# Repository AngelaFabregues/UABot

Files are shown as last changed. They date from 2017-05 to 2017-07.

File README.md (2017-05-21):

# UABot
Robot imprimible específicament dissenyat per fer un taller de robòtica educativa a la Universitat Autònoma de Barcelona (UAB).

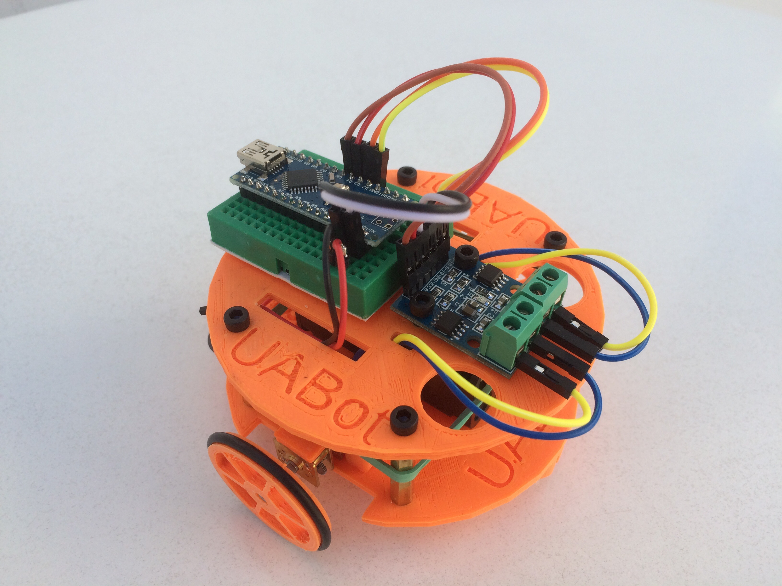
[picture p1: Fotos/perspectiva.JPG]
UABot


## Història
El Juliol 2017 es duu a terme un taller de robòtica anuncia com a Curs d'Estiu ICE de la UAB per a estudiants de 4t d'ESO i batxillerat. Durant el taller, els estudiants muntaran i programaran un robot dissenyat específicament per aquest taller. Aquest robot rep el nom d'UABot fent referència a la Universitat i a 'bot' (diminutiu de robot molt popular en grups de robòtica online).

## Disseny
Pel disseny de l'UABot s'ha buscat el robot que actualment cobreix millor les necessitats d'aquest taller i s'ha modificat per tal de satisfer-ne totes les necessitats. El robot en el que es basa principalment l'UABot és [Sapoconcho](https://bricolabs.cc/wiki/proyectos/sapoconcho).

A part de numeroses petites modificacions per a simplificar enormement la construcció del robot, l'UABot fa servir dues boles de moviment lliure enlloc d'una i porta les piles al centre suggectades per un elàstic. Això incrementa enórmement la robustessa i estabilitat del robot, i facilita el canvi de piles (que s'aconsella siguin recarregables).

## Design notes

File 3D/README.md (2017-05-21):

# UABot - 3D
El disseny dels components imprimibles s'ha realitzat íntegrament amb OpenScad. Això facilita la seva visualització i modificació.

## Impressió

Els components imprimibles a utilitzar al curs s'imprimeixen en diverses impressores replicables tipus Prusa IT2 i IT3 amb filament ABS o PLA de 3mm o 1'75 mm. Per a l'elecció s'ha tingut en compte sobretot la disponibilitat de les impressores en cada moment. Els components poden imprimir-se tots en una sola impressora i amb qualsevol d'aquests tipus de material i gruix de filament.

A més del curs d'estiu de l'ICE '' que ha motivat la creació de l'UABot, també es duu a terme un altre curs d'impressió 3D que proporciona la formació bàsica per a ser impressor 3D. Es tracta d'un curs molt interessant per qualsevol que vulgui crear un UABot imprimint-se les parts imprimibles.

## Parts imprimibles
* suport del motor: Facilita la fixació dels dos motors fent servir dos perns M2. També protegeix la connexió elèctrica al motor aportant una ranura per a enganxar-hi els cables.
* roda: 
* capa base: 
* capa control:

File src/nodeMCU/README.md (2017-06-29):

 

 per a poder installar l'entorn per a poder programar le nodeMCU 
 Open up Arduino, then go to the Preferences (File > Preferences). Then, towards the bottom of the window, 
 copy this URL into the “Additional Board Manager URLs” text box:
 
 http://arduino.esp8266.com/stable/package_esp8266com_index.json

Hit OK. Then navigate to the Board Manager by going to Tools > Boards > Boards Manager.
There should be a couple new entries in addition to the standard Arduino boards.
Look for esp8266. Click on that entry, then select Install.

tutorial interesante
http://www.instructables.com/id/Quick-Start-to-Nodemcu-ESP8266-on-Arduino-IDE/

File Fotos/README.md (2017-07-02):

UABot perspectiva
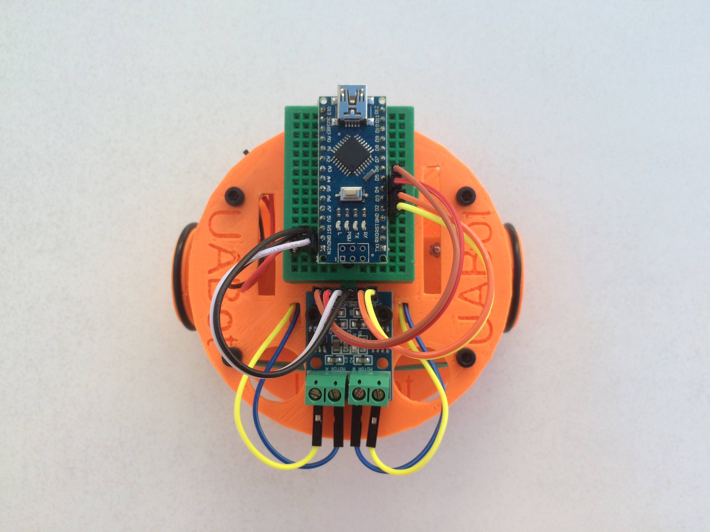
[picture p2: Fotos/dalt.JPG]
UABot dalt

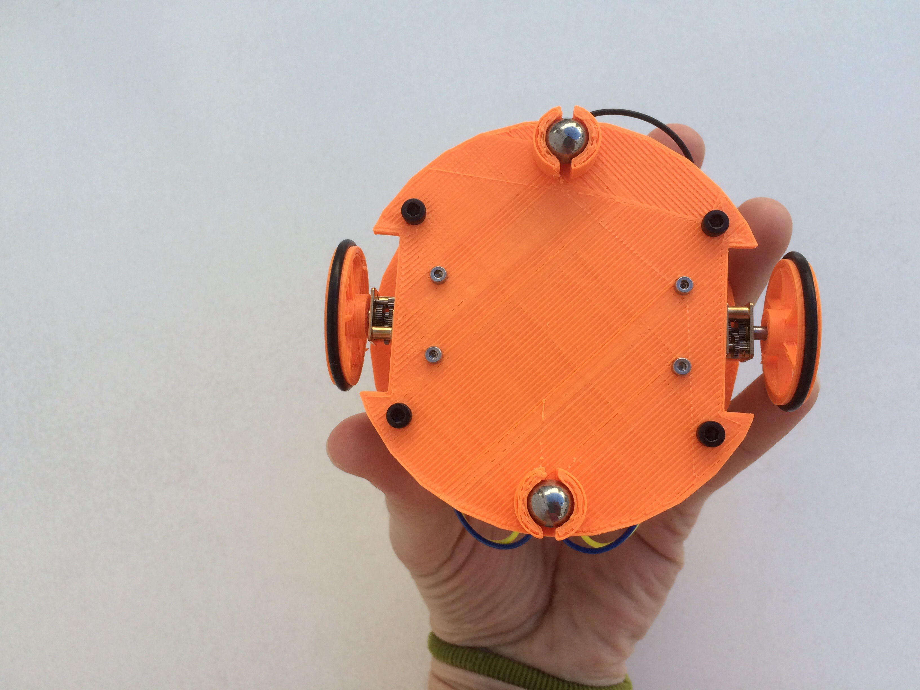
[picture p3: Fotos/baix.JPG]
UABot baix

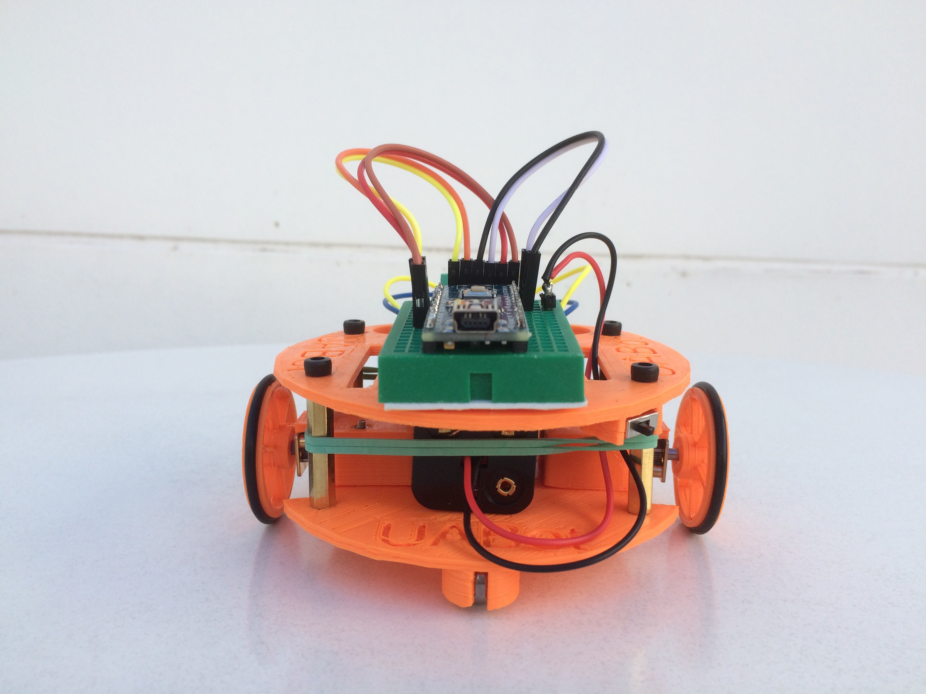
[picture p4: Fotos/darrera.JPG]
UABot darrera

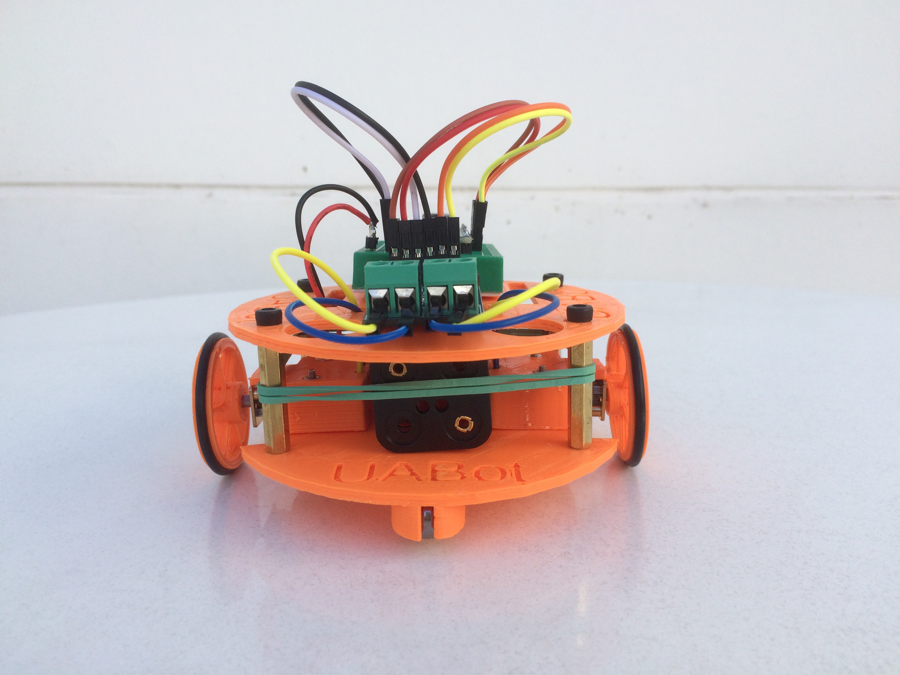
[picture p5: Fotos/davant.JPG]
UABot davant

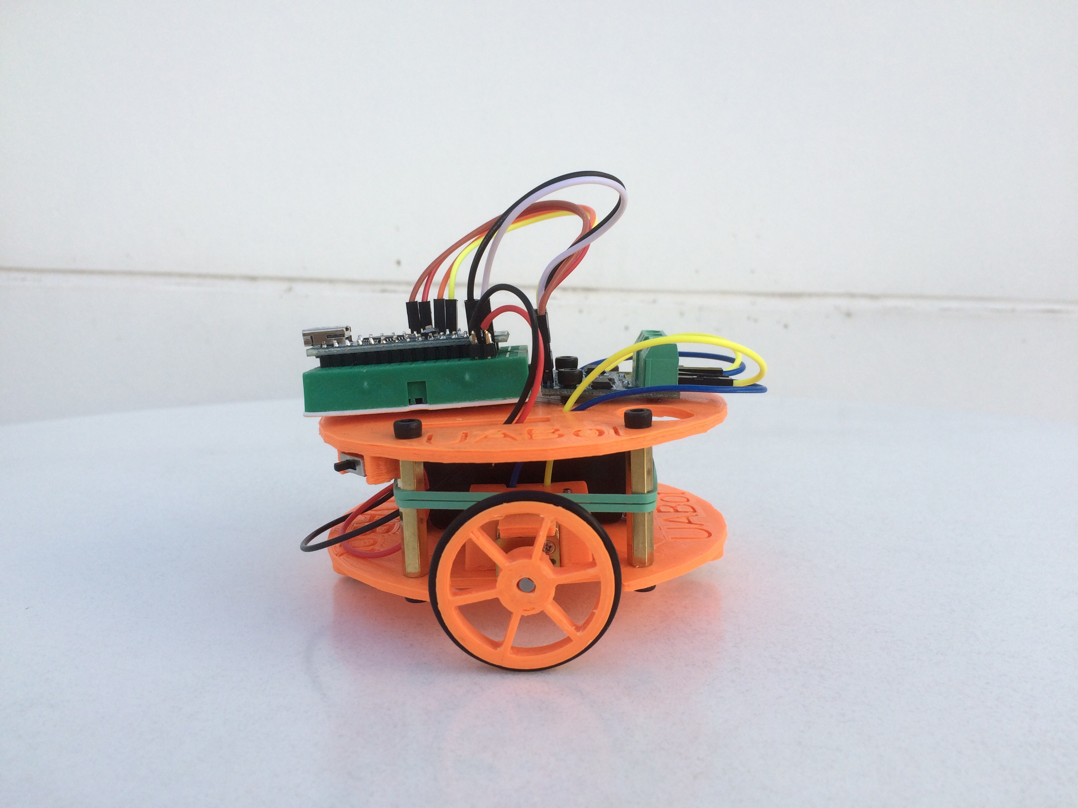
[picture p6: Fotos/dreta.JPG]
UABot dreta

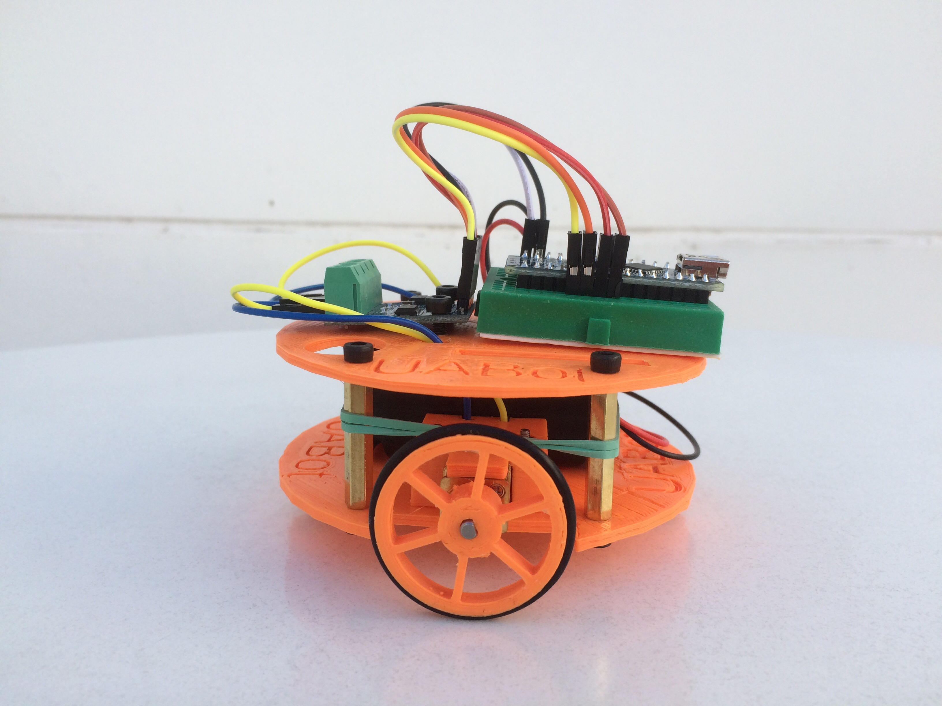
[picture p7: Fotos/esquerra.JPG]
UABot esquerra


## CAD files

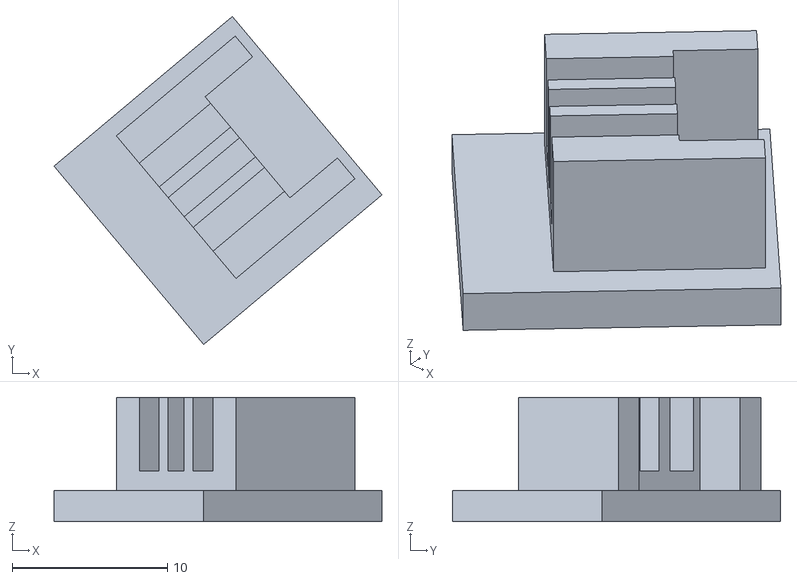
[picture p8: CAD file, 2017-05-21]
3D/suportMicroInterruptor.stl
21.1 x 21.1 x 8.00

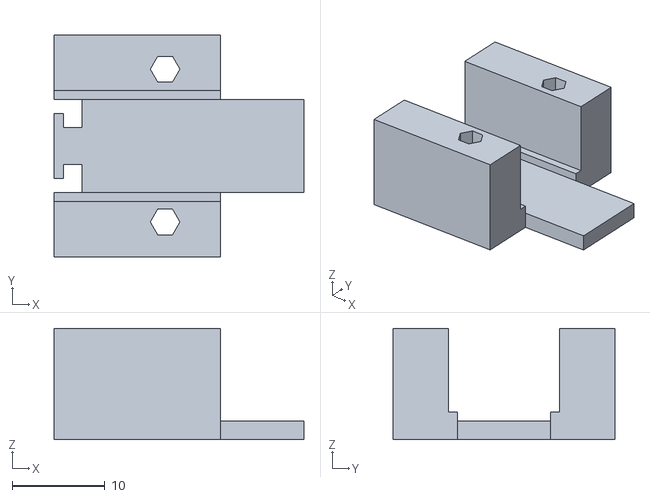
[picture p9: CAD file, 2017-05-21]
3D/suportMotor.stl
27.0 x 24.0 x 12.0

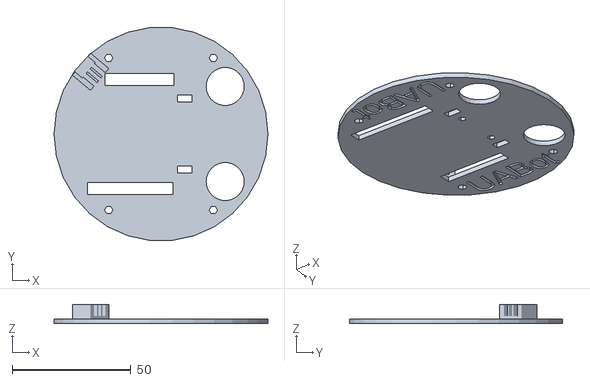
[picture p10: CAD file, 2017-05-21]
3D/capaControl.stl
90.0 x 89.5 x 8.00

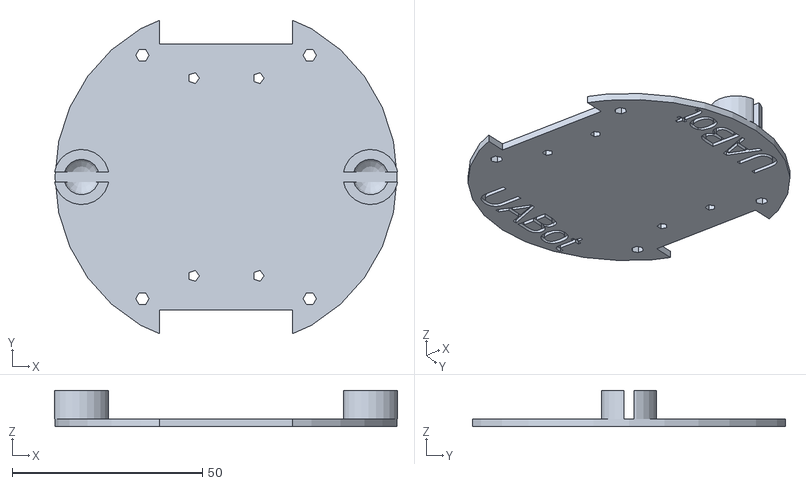
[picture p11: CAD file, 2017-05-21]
3D/capaBase.stl
90.2 x 82.4 x 9.50

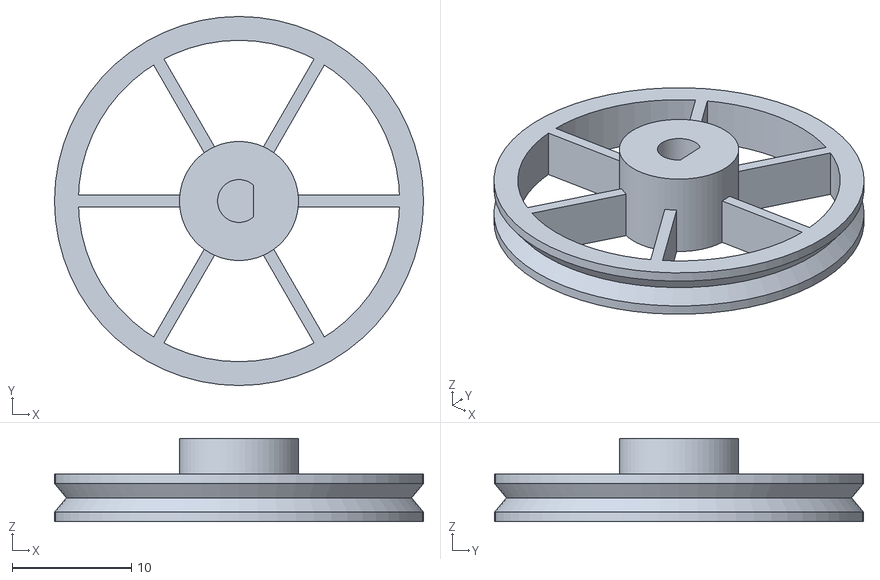
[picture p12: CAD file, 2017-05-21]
3D/roda.stl
31.0 x 31.0 x 7.00

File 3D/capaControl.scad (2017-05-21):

// Capa control amb forats per suggectar a placa base, forats per cables dels motors, forats per suggectar controllador motor, suport microinterruptor
module letter(l,s,h) {
	linear_extrude(height = h) {
		text(l, size = s, font = "Veltica", halign = "center", valign = "center", $fn = 16);
	}
}

module suportMicroInterruptor(t,r){
    rotate(r){ // interruptor baix
        translate(t){
            union(){ // support micro interruptor
                difference(){
                    translate([0,-3,1]){ // suport
                        cube(size = [12,10,6], center = true);
                    }
                    translate([0,1,1]){
                        cube(size = [8.5,6,6], center = true); // forat principal
    //                    cube(size = [8.3,6,10], center = true); // forat principal
                        translate([0,-5,0.75]){ // forats cables
                            translate([0,0,0]){
                                cube(size = [1.6,15,5], center = true);
                            }
                            translate([-2.7,0,0]){
                                cube(size = [2,15,5], center = true);
                            }
                            translate([2.7,0,0]){
                                cube(size = [2,15,5], center = true);
                            }
    /*                        translate([0,0,2]){
                                translate([0,0,0]){
                                    cube(size = [1.4,15,8], center = true);
                                }
                                translate([-2.5,0,0]){
                                    cube(size = [1.4,15,8], center = true);
                                }
                                translate([2.5,0,0]){
                                    cube(size = [1.4,15,8], center = true);
                                }
                            }
    */
                        }
                    }
                }
            }
        }
    }
}

rotate([180,0,0]){
difference(){
    cylinder(h = 2, r1 = 45, r2 = 45, center = true); // capa
    union(){ // forats perns M3 per suggectar a capa base
        r=1.75;
        translate([22,32,0]){
            cylinder(h = 4, r1 = r, r2 = r, center = true);
        }
        translate([22,-32,0]){
            cylinder(h = 4, r1 = r, r2 = r, center = true);
        }
        translate([-22,32,0]){
            cylinder(h = 4, r1 = r, r2 = r, center = true);
        }
        translate([-22,-32,0]){
            cylinder(h = 4, r1 = r, r2 = r, center = true); 
        }
    }
    // interruptor baix
    union(){ // forats perns M3 per suggectar controlador motor
        translate([10,0,0.2]){
            translate([0,9,0]){
                cylinder(h = 2, r1 = 1.5, r2 = 1.5, center = true);
            }
            translate([0,-9,0]){
                cylinder(h = 2, r1 = 1.5, r2 = 1.5, center = true); 
            }
            /*translate([13,9,0]){
                cylinder(h = 4, r1 = 1.5, r2 = 1.5, center = true);
            }
            translate([13,-9,0]){
                cylinder(h = 4, r1 = 1.5, r2 = 1.5, center = true); 
            }*/
        }
    }
    union(){ // forats cables dels motors
        translate([10,15,0]){
            cube(size = [6,3,4], center = true);
        }
        translate([10,-15,0]){
            cube(size = [6,3,4], center = true);
        }
    }
    union(){ // forats per cables 
        translate([-9,-23,0]){ // forat cables micro interruptor i alimentació
             cube(size = [29,5,4], center = true);
        }
        translate([-13,23,0]){
             cube(size = [36,5,4], center = true);
        }
    }
    union(){ // forats per cables
        rr=8;
        translate([27,-20,0]){ // forat cables micro interruptor i alimentació
             cylinder(h = 4, r1 = rr, r2 = rr, center = true);
        }
        translate([27,20,0]){
             cylinder(h = 4, r1 = rr, r2 = rr, center = true);
        }
    }
    union(){ // lletres UABot
        translate([0,35,0]){
            rotate([0,0,180]){
                letter("UABot",10,2);
            }
        }
        translate([0,-35,0]){
            rotate([0,0,0]){
                letter("UABot",10,2);
            }
        }
    }
}
/*// interruptor dalt
translate([10,0,2]){// pilars suggectar controlador motor
    translate([0,-9,0]){
        cylinder(h = 3, r1 = 1.5, r2 = 1.5, center = true); 
    }
    translate([13,9,0]){
        cylinder(h = 3, r1 = 1.5, r2 = 1.5, center = true);
    }
    translate([0,9,0]){
        cylinder(h = 3, r1 = 1.5, r2 = 1.5, center = true); 
    }
    translate([13,-9,0]){
        cylinder(h = 3, r1 = 1.5, r2 = 1.5, center = true);
    }
}*/

//suportMicroInterruptor([1,42.5,3],[0,0,135]); // interruptor dalt
suportMicroInterruptor([1,42.5,3],[180,0,-50]); // interruptor baix
}

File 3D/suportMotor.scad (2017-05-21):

// Suport del motor amb ranura per a enganxar cable, tope pel motor, solapa tope per a la goma, ranures per a encaixar femelles
rotate([180,0,0]){
difference(){
    union(){
        cube([18,24,12]); // volum principal
        translate([17,7,10]){ // solapa tope per a la goma
            cube([10,10,2]);
        }
    }
    union(){ // forats a fer
        union(){ // forat pel motor amb tope
            translate([-1,6,-1]){
                cube([20,12,10]);
                translate([0,1,0]){
                    cube([20,10,11]);
                }
            }
        }
        translate([12,3.7,-0.1]){ // forat per un pern M2
            cylinder(20,1.6,1.6,false);
            translate([0,0,12]){ // ranura per femella pern M2
                Hexagone(cle=4.3,h=3);
            }
        }
        translate([12,20.2,-0.1]){ // forat per un pern M2
            cylinder(20,1.6,1.6,false);
            translate([0,0,12]){ // ranura per femella pern M2
                Hexagone(cle=4.3,h=3);
            }
        }

        translate([-1,15.5,8]){ // forat per enganxar cable
            cube([3,1.5,10]); // entrada
            translate([2,-1.5,0]){ // dins
                cube([2,3,20]);
            }
        }
        translate([-1,7,8]){ // forat per enganxar cable
            cube([3,1.5,10]); // entrada
            translate([2,0,0]){  // dins
                cube([2,3,20]);
            }
        }

        
    }
}
}

//============================================================
// OpenSCAD
// Licence : LICENCE PUBLIQUE RIEN À BRANLER
// Licence : do What The Fuck you want to Public License
//============================================================
/*

	Usage:
	use <Hexagones.scad>;
	Pour créer des jeux, des têtes de vis...

*/
//------------------------------------------------------------
// Hexagone
// cle	écart, ex: clé de 12 alors cle=12
// h		hauteur
//------------------------------------------------------------
module Hexagone(cle,h)
{
	angle = 360/6;		// 6 pans
	cote = cle * cot(angle);
	echo(angle, cot(angle), cote);
	echo(acos(.6));

	union()
	{
		rotate([0,0,0])
			cube([cle,cote,h],center=true);
		rotate([0,0,angle])
			cube([cle,cote,h],center=true);
		rotate([0,0,2*angle])
			cube([cle,cote,h],center=true);
	}

// Vérification par un cercle de taille cle
//	#cylinder(r=cle/2,h=2*h,center=true);
//	%circle(r=cote,center=true);
//	#cube([cote,cote,1]);
}

//------------------------------------------------------------
// Fonction cotangente
// Permet d'avoir les bones dimensions
// utiliser $fn n'est pas bon
//------------------------------------------------------------
function cot(x)=1/tan(x);

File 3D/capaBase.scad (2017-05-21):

// Capa base amb forats per suggectar la placa control, forats per suggectar els motors, suports de bolles de gir lliure i ranura per a rodes, gravat UABot
module letter(l,s,h) {
	linear_extrude(height = h) {
		text(l, size = s, font = "Veltica", halign = "center", valign = "center", $fn = 16);
	}
}

module suport_bola(t){
// suport bola de lliure moviment tamany 9.5 mm diametre
    translate(t){
        h_base=2;
        h_cilindre=7.5;
        r_cilindre=7.25;
        d_esfera=10.5;
        difference(){
            union(){
        // cube([20,20,h_base], center=true); // base ideal
                translate([0,0,h_base/2+h_cilindre/2]){
                    cylinder(h = h_cilindre, r1 = r_cilindre, r2 = r_cilindre, center = true);
                }
            }
            translate([0,0,h_base/2+h_cilindre/2+1]){
                cube([r_cilindre*2,2.5,h_cilindre+2], center=true);
                    sphere(d=10);
            }
            translate([0,0,h_base/2+d_esfera/2]){
                sphere(d=d_esfera);
            }
        }
    }
}
rotate([180,0,0]){
difference(){
    union(){
        cylinder(h = 2, r1 = 45, r2 = 45, center = true); // capa
        rotate([180,0,0]){
            suport_bola([38,0,0]);
            suport_bola([-38,0,0]);
        }
    }
    union(){ // ranures per a rodes
        translate([0,40,0]){
            cube([35,10,4], center=true);
        }
        translate([0,-40,0]){
            cube([35,10,4], center=true);
        }
    }
    union(){ // forats per a support motor
        foratPernM2=1.5;
        translate([0,26,0]){
            translate([8.5,0,0]){
                cylinder(h = 4, r1 = foratPernM2, r2 = foratPernM2, center = true);
            }
            translate([-8.5,0,0]){
                cylinder(h = 4, r1 = foratPernM2, r2 = foratPernM2, center = true);
            }
        }
        translate([0,-26,0]){
            translate([8.5,0,0]){
                cylinder(h = 4, r1 = foratPernM2, r2 = foratPernM2, center = true);
            }
            translate([-8.5,0,0]){
                cylinder(h = 4, r1 = foratPernM2, r2 = foratPernM2, center = true);
            }
        }
    }
    union(){ // forats perns M3 per suggectar a capa base
        r=1.75;
        translate([22,32,0]){
            cylinder(h = 4, r1 = r, r2 = r, center = true);
        }
        translate([22,-32,0]){
            cylinder(h = 4, r1 = r, r2 = r, center = true);
        }
        translate([-22,32,0]){
            cylinder(h = 4, r1 = r, r2 = r, center = true);
        }
        translate([-22,-32,0]){
            cylinder(h = 4, r1 = r, r2 = r, center = true); 
        }
    }
    union(){ // lletres UABot
        translate([35,0,0]){
            rotate([0,0,90]){
                letter("UABot",10,2);
            }
        }
        translate([-35,0,0]){
            rotate([0,0,-90]){
                letter("UABot",10,2);
            }
        }
    }
}
}

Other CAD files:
3D/roda.scad
3D/suportMicroInterruptor.scad

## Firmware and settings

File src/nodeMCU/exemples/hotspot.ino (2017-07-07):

#include <ESP8266WiFi.h>

#include <WiFiClient.h>

#include <ESP8266WebServer.h>

const char *ssid = "test";

const char *password = "password";

int i = 0;

ESP8266WebServer server(80);

void handleRoot() {
i++;
server.send(200, "text/html", "<h1>You are connected "+String(i)+"</h1><a href=\"/run\">RUN</a><br><a href=\"/stop\">STOP</a>");

}

void handleRun(){
  digitalWrite(2,LOW);
  server.send(200, "text/html", "<h1>S'hauria d'encendre el led.</h1>");

}


void handleStop(){
  digitalWrite(2,HIGH);
  server.send(200, "text/html", "<h1>S'hauria de parar el led.</h1>");

}

void setup() {

delay(1000);
pinMode(2,OUTPUT);
Serial.begin(115200);

Serial.println();

Serial.print("Configuring access point...");

WiFi.softAP(ssid, password);

IPAddress myIP = WiFi.softAPIP();

Serial.print("AP IP address: ");

Serial.println(myIP);

server.on("/", handleRoot);

server.on("/run", handleRun);
server.on("/stop", handleStop);

server.begin();

Serial.println("HTTP server started");

}

void loop() {

server.handleClient();

}

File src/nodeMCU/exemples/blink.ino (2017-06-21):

#define LED_BUILTIN 2
 
void setup() {
  // El LED integrado está conectado al pin 2.
  pinMode(LED_BUILTIN, OUTPUT);
}
 
void loop() {
  // Encender el LED (Está conectado con una resistencia pull-up,
  // por eso se enciende si el pin está a nivel bajo)
  digitalWrite(LED_BUILTIN, LOW);
  delay(1000); // Esperar un segundo
  // Apagar el LED
  digitalWrite(LED_BUILTIN, HIGH);
  delay(1000); // Esperar un segundo
}

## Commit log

2017-04-22 Disseny 3D suport motor
    [suportMotor.scad, suportMotor.stl]
2017-04-22 Support de motor: ampliats forats perns, ampliat forat entrada cable, ampliada amplada support, reduit distancia retracció per a impressió.
    [suportMotor.scad, suportMotor.stl]
2017-04-22 Support motor: afegida solapa tope per a la goma, afegit tope pel motor, modificats lleugerament forats pels cables.
    [suportMotor.scad, suportMotor.stl]
2017-04-23 Support motor: afegida ranura per a femella pern M2
    [suportMotor.scad, suportMotor.stl]
2017-04-23 Support motor: ampliades ranures per a femella pern M2
    [suportMotor.scad, suportMotor.stl]
2017-04-23 Capa Base: base con dos bolas locas y agujeros para sujetar motores.
    [CapaBase.blend, CapaBase.stl]
2017-04-23 Support motor: reduides ranures per a femella pern M2
    [suportMotor.scad, suportMotor.stl]
2017-04-29 Rodes del sapoconcho kiss
    [roda.scad, roda.stl]
2017-04-29 Canviant nom capa base.
    [CapaBase.blend, CapaBase.stl]
2017-04-29 capa control
    [capaControl.scad, capaControl.stl]
2017-04-29 Capa control: reduir forats cable motor.
    [capaControl.scad, capaControl.stl]
2017-04-29 Capa control: afegit suport microinterruptor, forats cable micro interruptor, modificats forats cables motor, afegits pilars suport controlador motor, reduits forats perns M3.
    [capaControl.scad, capaControl.stl]
2017-04-29 Capa control: afegit text UABot.
    [capaControl.scad, capaControl.stl]
2017-04-30 Capa control: interruptor a baix.
    [capaControl.scad]
2017-04-30 Capa control: support micro interruptor senzill.
    [capaControl.scad]
2017-04-30 Suport bola: reduccio diametre esfera, ampliacio diametre cilindre, reduccio ranura interna.
    [suportBola.scad, suportBola.stl]
2017-04-30 Suport bola: ampliant diàmetre esfera.
    [suportBola.scad, suportBola.stl]
2017-04-30 Capa control: afegits molts forats per cables i rectificada posicio del suport de linterruptor.
    [capaControl.scad, capaControl.stl]
2017-04-30 Capa base: suport boles i lletres. Capa control: us de moduls.
    [capaBase.scad, capaBase.stl, capaControl.scad]
2017-05-03 Roda: canvi format codi per a seguir el format de la resta de codi scad del UABot.
    [roda.scad]
2017-05-03 Roda: reduir forat eix i posar-hi un tope.
    [roda.scad, roda.stl]
2017-05-21 Esborrant blender de capa base que ja no es fa servir.
    [capaBase.blend]
2017-05-21 Roda: reducció diametre eix.
    [roda.scad, roda.stl]
2017-05-21 suportMotor: reduida ranura femella, ampliat forat perns.
    [suportMotor.scad, suportMotor.stl]
2017-05-21 capaBase: ampliats forats pern M2 pel suport del motor.
    [capaBase.scad, capaBase.stl]
2017-05-21 capaControl: ampliades ranures laterals del microinterruptor.
    [capaControl.scad, capaControl.stl]
2017-05-21 Invertits dissenys per a facilitar el posterior filetejat.
    [capaBase.scad, capaBase.stl, capaControl.scad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]
2017-05-21 Suport micro interruptor separat.
    [suportMicroInterruptor.scad, suportMicroInterruptor.stl]
2017-06-21 exemple hotspot validat
    Obre una xarxa adhoc i permet connectar-s'hi a la ip 192.168.4.1. Per cada petició HTTP amb un navegador a aquesta ip respon amb un missatge "You are connected X" on X és un número que es va incremen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
    La prova de connexió l'hem fet des d'un iPhone.
2017-06-21 Prova blink validada
    En rebre corrent, fa blink al pin 2.
2017-06-21 Create README.md
    how to add the nodeMCU board to the arduino IDE
2017-06-28 Create comunicatingArduinos
    information concerning how to comunicate two arduinos to send information from one to the another one
2017-07-02 Mostrant les fotos al readme.
